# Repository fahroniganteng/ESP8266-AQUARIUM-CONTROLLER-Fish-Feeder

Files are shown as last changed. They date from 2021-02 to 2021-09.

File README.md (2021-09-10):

# ESP8266-AQUARIUM-CONTROLLER-Fish-Feeder
Control aquarium with ESP8266 - Fish Feeder, Lamp, Pump

## Feature
- Wifi connection
- Web base admin
- Offline / Online mode
- Standalone (required NTP connection in online mode)
- Pump control (ON/OFF).
- Fish feeder schedule.
- RGB lamp control & schedule ON/OFF in online mode.

## Demo
DEMO (https://youtu.be/GxMegb_iBR0)

## Instalation guide
DEMO (https://youtu.be/HuCPMu3hP7A)
> video in indonesian language

- Install arduino IDE from [arduino web](https://www.arduino.cc/)
- Install driver CH340 [check here](https://learn.sparkfun.com/tutorials/how-to-install-ch340-drivers/all)
- Upload sketch :
	- Add ESP8266 board to arduino IDE [check here](https://github.com/esp8266/Arduino)
	- Upload sketch
- Upload HTML file:
	- Install filesystem plugin to arduino IDE [check here](https://github.com/esp8266/arduino-esp8266fs-plugin)
	- Upload HTML file
	> NOTE:  
	> When uploading filesystem make sure the serial monitor (arduino IDE) is closed

## Components
- ESP8266 board (Wemos, nodemcu, etc)
- Led strip 12v (common anode)
- Mosfet N channel (can use ULN2003 if using short led strip/ low ampere)
- Servo SG90
- Relay modul / shield
- Mechanical feeder (use 3D printer, check model in 3D folder)
- 12V Power supply
- 5V power supply (or use step down 12v to 5v)
- Box (optional, check model in 3D folder)

## Wiring
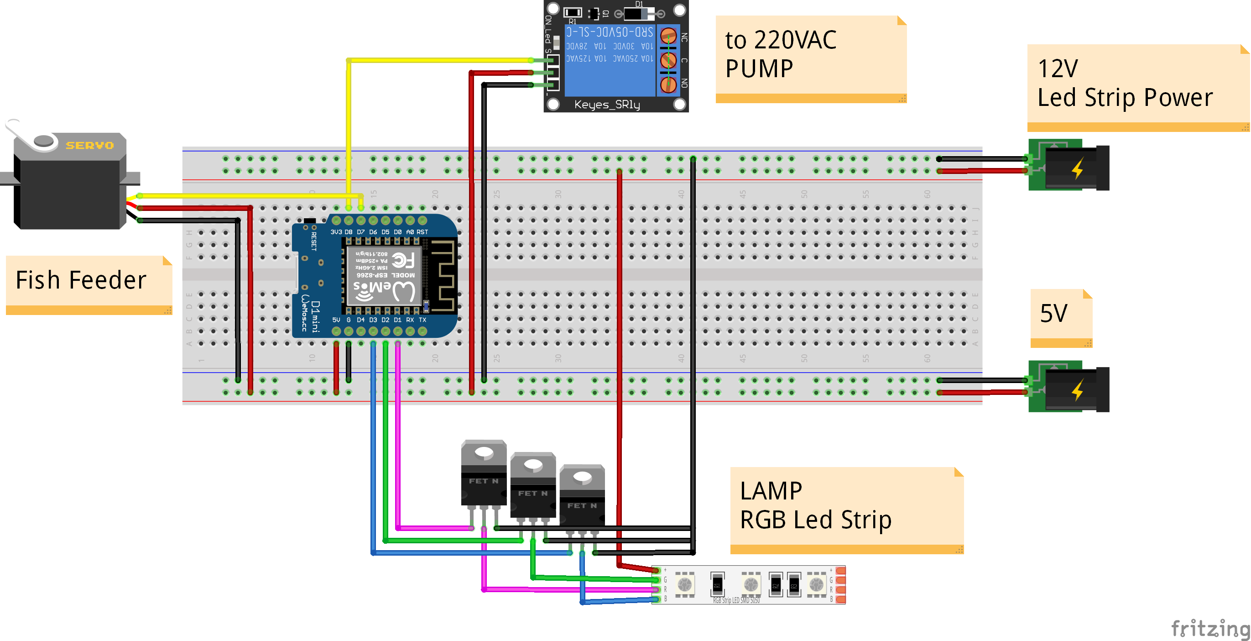
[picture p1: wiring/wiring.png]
Wiring

 - D1 : Red led strip
 - D2 : Green led strip
 - D3 : Blue led strip
 - D7 : Servo
 - D8 : Relay

## Mechanical Feeder
Mechanical feeder made with 3d printer, check on 3D folder for models.
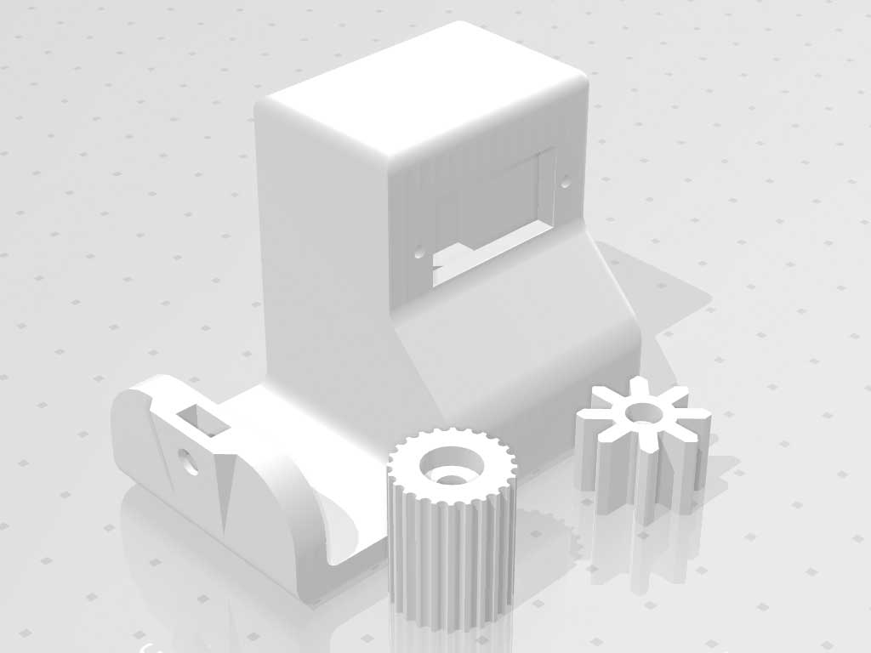
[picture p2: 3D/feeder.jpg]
feeder1

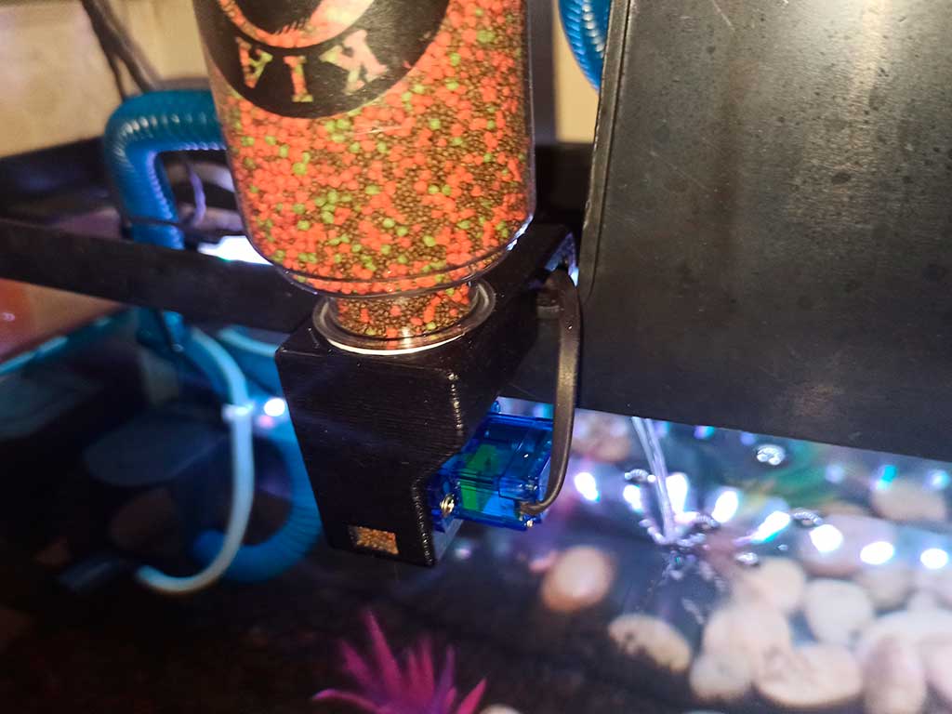
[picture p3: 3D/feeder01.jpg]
feeder2

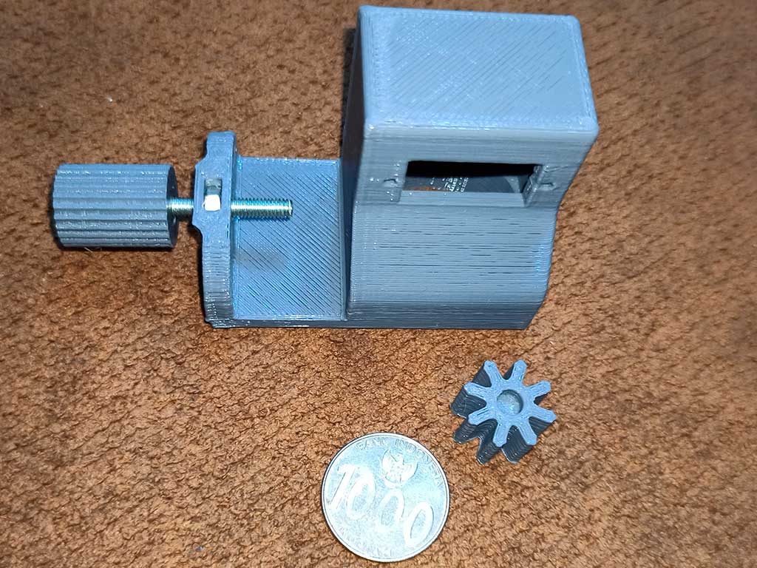
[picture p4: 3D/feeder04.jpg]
feeder3

> Mechanical feeder remixes from [here](https://www.thingiverse.com/thing:2921447)
## Usage
Default setting is offline mode (device becomes wifi access point) :
- Connect to board with wifi 
	- Default SSID = AQUARIUM
	- No password
- Open web address http://10.10.10.10/
> NOTE:  
> ESP8266 is low processor, too many web connections will be slow.

Set up wifi connection and NTP to change online mode.  
- offline mode ==> schedule feeders based on duration.
- online mode ==> schedule feeders based on time.

If internet connection down or can't get time from NTP server, it will auto switch to offline mode, and duration calculated from last feed.  

## License and credits
My code under MIT license, other libraries follow their own license.
- Timer.h
- NTPClient.h
- Jquery.js
- Bootstrap
- etc...

## Donation  
Support me  
- [Send me coffee](https://sociabuzz.com/fahroniganteng/tribe)
- [or maybe ice cream](https://trakteer.id/fahroniganteng/tip)

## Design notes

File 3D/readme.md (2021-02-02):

# 3D Printer File
## feeder.stl
Fish Feeder
- 1x M4 bolt
- 1x servo SG90

## box.stl
Box for controller
- 2x M3 bolt
- acrylic

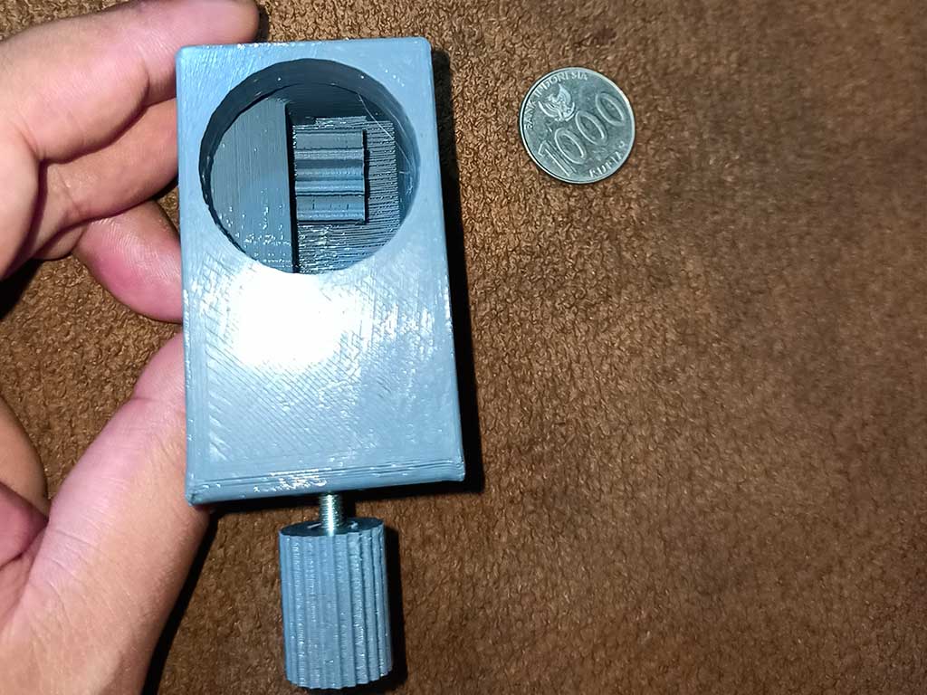
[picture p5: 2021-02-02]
3D/feeder03.jpg

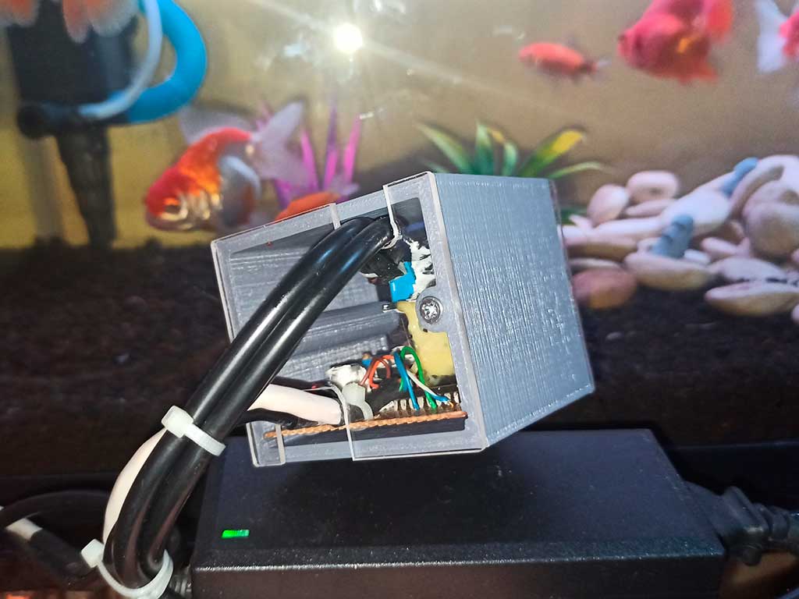
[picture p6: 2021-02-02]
3D/box01.jpg

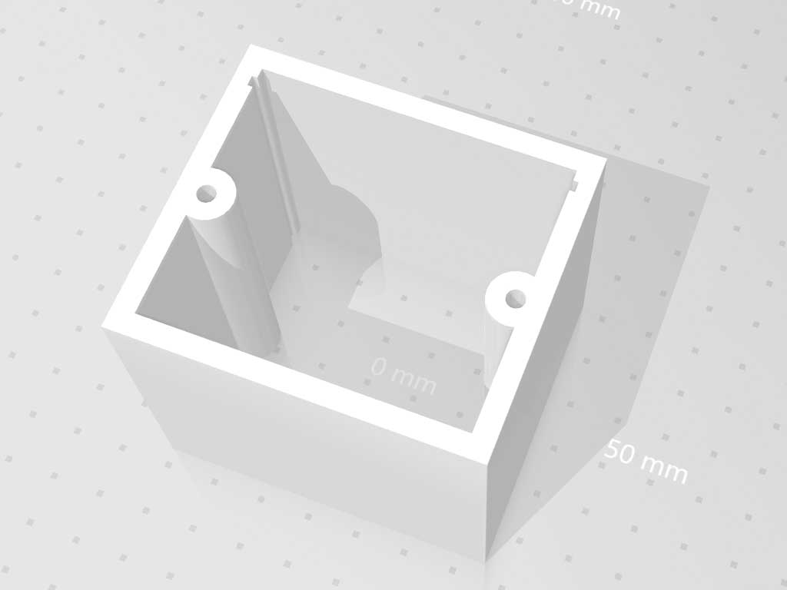
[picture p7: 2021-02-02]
3D/box.jpg

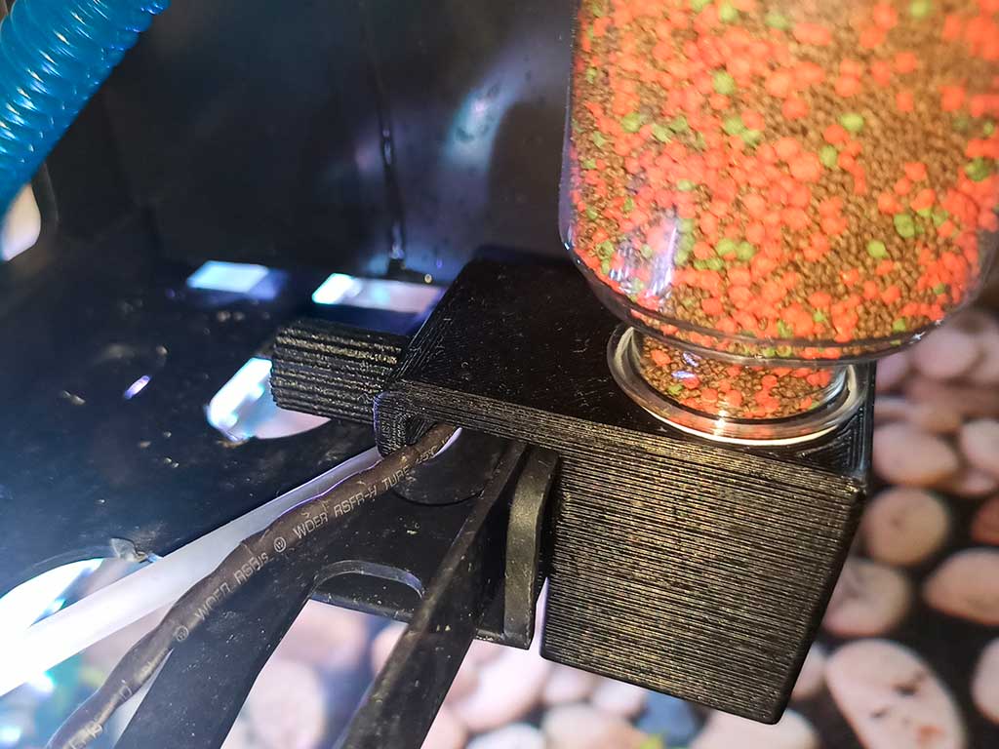
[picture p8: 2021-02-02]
3D/feeder02.jpg

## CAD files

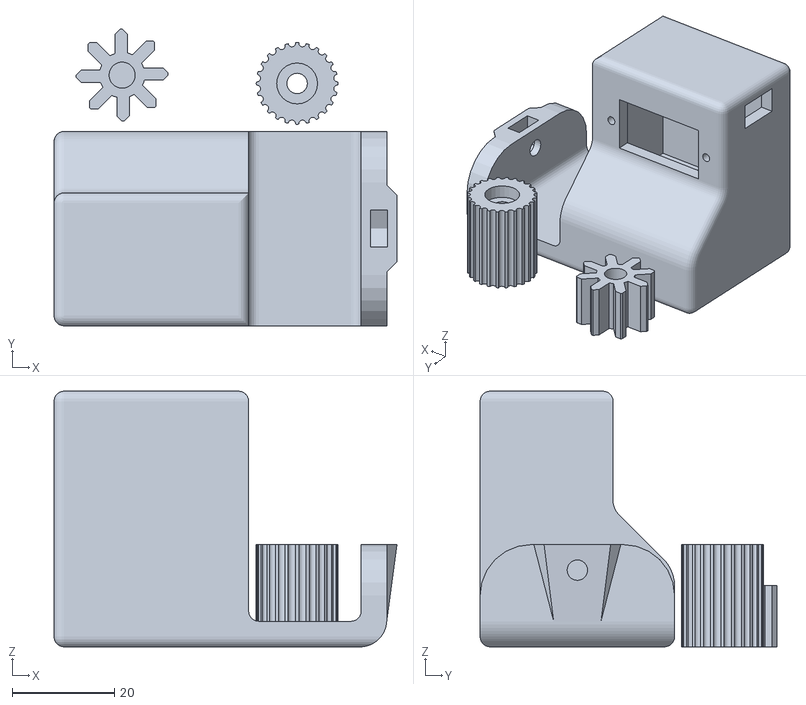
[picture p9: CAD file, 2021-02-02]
3D/feeder.stl
67.0 x 58.0 x 50.0

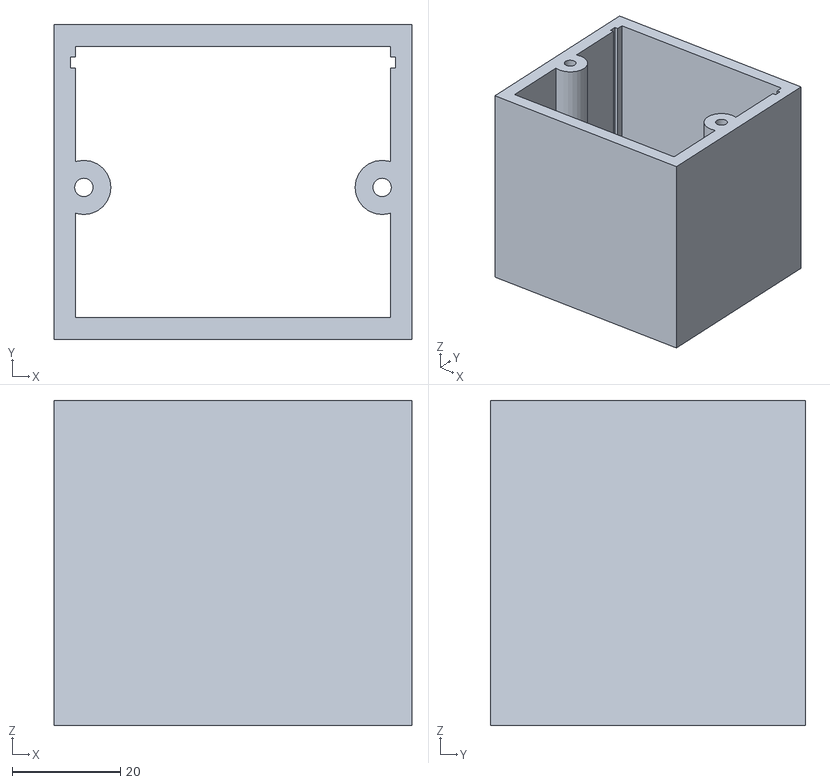
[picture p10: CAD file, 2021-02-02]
3D/box.stl
66.0 x 58.0 x 60.0

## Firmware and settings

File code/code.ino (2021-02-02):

/*
 * AQUARIUM CONTROLLER
 * *********************************************************************************
 * Code by : fahroni|ganteng 
 * Contact me : fahroniganteng@gmail.com
 * License : MIT
 * --------------------------
 * 
 * PIN use on WEMOS D1 Mini
 * D1 : Pin RED led strip
 * D2 : Pin Green led strip
 * D3 : Pin Blue led strip
 * D4 = LED_BUILTIN : not connect ==> for indicator light
 * D7 : Servo
 * D8 : Relay
 * 
 */


#include "NTPClient.h"
#include <ESP8266WiFi.h>
#include <WiFiUdp.h>
#include <ESP8266WebServer.h>
#include <EEPROM.h>
#include "Timer.h"
#include "time.h"
#include <FS.h>   //Include File System Headers
#include <Servo.h>




//Maping PIN ESP8266 board
const int PIN[9] = {D0,D1,D2,D3,D4,D5,D6,D7,D8};// all digital pin ESP8266
const int PIN_LED[3] = {D1,D2,D3}; // to RGB PIN --> LED STRIP is common cathode (-), but if use mosfet will be inverse --> analog write 0 = off, 255 = max brightness
#define PIN_SERVO D7 // to servo
#define PIN_PUMP D8 // to relay

// speed servo ==> ms/degree
#define SERVOSPEED 2.5

// fn get size of int array
#define arrSize(x)   (sizeof(x) / sizeof(x[0]))

// fn Calculate time
#define SECS_PER_MIN  (60UL)
#define SECS_PER_HOUR (3600UL)
#define SECS_PER_DAY  (SECS_PER_HOUR * 24L)

#define getSEC(_time_) (_time_ % SECS_PER_MIN)  
#define getMIN(_time_) ((_time_ / SECS_PER_MIN) % SECS_PER_MIN)
#define getHOUR(_time_) (( _time_% SECS_PER_DAY) / SECS_PER_HOUR)
#define getDAY(_time_) ( _time_ / SECS_PER_DAY)

// Debuging
#define DEBUG 0   // Enable or disable ==> set 1 to enable serial debuging
#if DEBUG
  #define PRINT(s)     { Serial.print(s); }
  #define PRINTLN(s)     { Serial.println(s); }
#else
  #define PRINT(s)
  #define PRINTLN(s)
#endif

//Setting soft AP
const char* ssid = "AQUARIUM";
const char* passphrase = "";//blank = no password
const char* wifiHostName = "AQUARIUM"; //host name device (like computer name if read from network)
IPAddress local_IP(10,10,10,10);
IPAddress gateway(10,10,10,10);
IPAddress subnet(255,255,255,0);
//web server
ESP8266WebServer server(80);

// servo
Servo s;


/*
 * GLOBAL VARIABLE
 * ******************************************************************************************
 */
//Timer ---------------------------------------------------------------
Timer tmr;

//UP time -------------------------------------------------------------
long secUpTime = 0; // counter uptime in second --> default first boot = 0 second
String shUpTime;    // show UP Time (view up time)


//NTP & WIFI ----------------------------------------------------------
WiFiUDP ntpUDP;     // send request time to NTP server
NTPClient timeClient(ntpUDP); 
float timeZone;     // buffer time zona --> if in half hour like GMT -3:30 = -3.5 --> so use float
String e_ssid; // buf SID wifi name
String e_pass; 
String e_ntp; 
String e_gmt; 

// FISH FEEDER ---------------------------------------------------------
String feed_time[5]; // array buffer eeprom feed time {feed1, feed2, ... feed5)
int feed_level,feed_loop,feed_duration; // buffer feed
String nextFeed;

// LAMP ----------------------------------------------------------------
String lamp_time[2];//{off,on}
String lamp_color;
int lamp_status = 1,lamp_brig,lamp_mode,lamp_speed;

// PUMP ----------------------------------------------------------------
int pump_status = 1;

/*
 * NOTE :
 * lamp and pump always start on boot...
 */




/*
 * FUNCTION
 * *****************************************************************************************
 */
// FEEDER -------------------
int secondAfterFeeder = 0;
void feedFish(){
  int moveDegree = map(feed_level,1,10,30,180);
  int moveTime   = SERVOSPEED * moveDegree;
  moveTime       = moveTime<150?150:moveTime;//minimal 150ms
  for(int i=0;i<feed_loop;i++){
    PRINTLN("Feed fish "+String(moveDegree)+" deg");
    s.write(moveDegree);
    delay(moveTime);
    s.write(0);
    delay(moveTime);
  }
  secondAfterFeeder = 0;
}

// UP TIME -------------------
void uptime(){
  char buf[50];//buffer
  secUpTime++; // max long datatype = 2,147,483,647 second = 69 year
  //secUpTime = secUpTime<0?0:secUpTime; // after 2,147,483,647 + 1 = -2147483648 ==> impossible run until 69 year ^___^
  
  snprintf(buf, 50, "%ld Day %02d:%02d:%02d",getDAY(secUpTime),getHOUR(secUpTime),getMIN(secUpTime),getSEC(secUpTime));
  shUpTime = String(buf);
}

// MOVE TO OTHER FILE --------------------------
#include "fnEEPROM.h" // mapping eeprom
#include "fnWifi.h"   // function conection wifi
#include "fnNTP.h"    // get time from NTP
#include "fnLamp.h"   // Lamp handle
#include "fnHtml.h"   // for handle HTML request (from web browser)



// CHECK EVERY 1 SECOND -----------------------
int countApMode = 0;

void check_1s(){
  getNtpDate(); //check NTP
  uptime(); // check uptime
  secondAfterFeeder++;
  
  // IF OFFLINE OR not connect NTP server
  if (WiFi.status() != WL_CONNECTED || ntp_datetime == "--no data--" ){ 
    // run offline fish feeder
    if(feed_duration * 60 * 60 < secondAfterFeeder)
      feedFish();

    // Offline next feed
    char buf[50];//buffer
    int secNextFeed = feed_duration * 60 * 60 - secondAfterFeeder;
    snprintf(buf, 50, "%02d:%02d:%02d",getHOUR(secNextFeed),getMIN(secNextFeed),getSEC(secNextFeed));
    nextFeed = buf;

    // try connect every 60 second, if SSID in EEPROM is set. ==> not set = "__DEFAULT_WIFI__"
    if(e_ssid!="__DEFAULT_WIFI__" && countApMode > 60){
      connectWifi();
      countApMode=0; // counting form zero again, until 60 second try connect again...
    }
    else 
      countApMode++;
  }
  else {
    //check every minutes (ONLINE MODE)
    if(arr_time[2]=="00"){
      String buf = arr_time[0] + ":" + arr_time[1];
      // check feed schedule 
      for(int i=0; i<5; i++){
        if(feed_time[i] == buf){
          feedFish();
          break;
        }
      }
      //check lamp schedule ==> if schedule ON same with OFF ==> lamp always ON
      if(lamp_time[1]==buf)fn_RGBstart();
      else if(lamp_time[0]==buf)fn_RGBstop();
    }
    countApMode=0;
  }
}











void setup() {
  //for debug
  Serial.begin(115200);

  //read EEPROM data
  EEPROM.begin(512);
  readAllDataEEPROM();

  // for file system (html and friends on flash memory)
  SPIFFS.begin();

  // set all digital pin OUTPUT
  for(int i=0; i<arrSize(PIN); i++){
    pinMode(PIN[i], OUTPUT);
    digitalWrite(PIN[i], LOW);
  }

  // Servo PIN
  s.attach(PIN_SERVO);
  s.write(0);
  
  // Turn ON Pump
  digitalWrite(PIN_PUMP,HIGH);

  // Turn ON Lamp
  fn_RGBstart();
  
  //Wifi start
  WiFi.persistent(false);
  PRINTLN("Connecting wifi...");
  connectWifi();
  
  //start http server
  server.begin();
  serverOnHandleClient();
  PRINTLN("HTTP server started");
  
  //turn off LED_BUILTIN; --> LED_BUILTIN = D4 (WEMOS D1 MINI)
  digitalWrite(LED_BUILTIN,HIGH);// HIGH = off --> i dont know why... :D
  
  //NTP
  ntpInit();
  delay(1000);
  tmr.every(3600000,[](){//force update NTP every 1 hour
    timeClient.forceUpdate();
  });

  // Check every 1 second
  delay(100);
  tmr.every(1000,check_1s);
}
void loop() {
  tmr.update(); // update timer
  server.handleClient(); // check http client request
}

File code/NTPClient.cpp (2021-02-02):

/**
 * The MIT License (MIT)
 * Copyright (c) 2015 by Fabrice Weinberg
 *
 * Permission is hereby granted, free of charge, to any person obtaining a copy
 * of this software and associated documentation files (the "Software"), to deal
 * in the Software without restriction, including without limitation the rights
 * to use, copy, modify, merge, publish, distribute, sublicense, and/or sell
 * copies of the Software, and to permit persons to whom the Software is
 * furnished to do so, subject to the following conditions:
 * The above copyright notice and this permission notice shall be included in all
 * copies or substantial portions of the Software.
 * THE SOFTWARE IS PROVIDED "AS IS", WITHOUT WARRANTY OF ANY KIND, EXPRESS OR
 * IMPLIED, INCLUDING BUT NOT LIMITED TO THE WARRANTIES OF MERCHANTABILITY,
 * FITNESS FOR A PARTICULAR PURPOSE AND NONINFRINGEMENT. IN NO EVENT SHALL THE
 * AUTHORS OR COPYRIGHT HOLDERS BE LIABLE FOR ANY CLAIM, DAMAGES OR OTHER
 * LIABILITY, WHETHER IN AN ACTION OF CONTRACT, TORT OR OTHERWISE, ARISING FROM,
 * OUT OF OR IN CONNECTION WITH THE SOFTWARE OR THE USE OR OTHER DEALINGS IN THE
 * SOFTWARE.
 */

#include "NTPClient.h"

NTPClient::NTPClient(UDP& udp) {
  this->_udp            = &udp;
}

NTPClient::NTPClient(UDP& udp, long timeOffset) {
  this->_udp            = &udp;
  this->_timeOffset     = timeOffset;
}

NTPClient::NTPClient(UDP& udp, const char* poolServerName) {
  this->_udp            = &udp;
  this->_poolServerName = poolServerName;
}

NTPClient::NTPClient(UDP& udp, const char* poolServerName, long timeOffset) {
  this->_udp            = &udp;
  this->_timeOffset     = timeOffset;
  this->_poolServerName = poolServerName;
}

NTPClient::NTPClient(UDP& udp, const char* poolServerName, long timeOffset, unsigned long updateInterval) {
  this->_udp            = &udp;
  this->_timeOffset     = timeOffset;
  this->_poolServerName = poolServerName;
  this->_updateInterval = updateInterval;
}

void NTPClient::begin() {
  this->begin(NTP_DEFAULT_LOCAL_PORT);
}

void NTPClient::begin(int port) {
  this->_port = port;

  this->_udp->begin(this->_port);

  this->_udpSetup = true;
}

bool NTPClient::forceUpdate() {
  #ifdef DEBUG_NTPClient
    Serial.println("Update from NTP Server");
  #endif
  this->sendNTPPacket();

  // Wait till data is there or timeout...
  byte timeout = 0;
  int cb = 0;
  do {
    delay ( 10 );
    cb = this->_udp->parsePacket();
    if (timeout > 100) return false; // timeout after 1000 ms --> default 100 (1000ms) tak ganti 10 (100ms)
    timeout++;
  } while (cb == 0);
  this->_lastUpdate = millis() - (10 * (timeout + 1)); // Account for delay in reading the time

  this->_udp->read(this->_packetBuffer, NTP_PACKET_SIZE);

  unsigned long highWord = word(this->_packetBuffer[40], this->_packetBuffer[41]);
  unsigned long lowWord = word(this->_packetBuffer[42], this->_packetBuffer[43]);
  // combine the four bytes (two words) into a long integer
  // this is NTP time (seconds since Jan 1 1900):
  unsigned long secsSince1900 = highWord << 16 | lowWord;

  this->_currentEpoc = secsSince1900 - SEVENZYYEARS;
  return true;
}

bool NTPClient::update() {
  if ((millis() - this->_lastUpdate >= this->_updateInterval)     // Update after _updateInterval
    || this->_lastUpdate == 0) {                                // Update if there was no update yet.
    if (!this->_udpSetup) this->begin();                         // setup the UDP client if needed
    return this->forceUpdate();
  }
  return true;
}

unsigned long NTPClient::getEpochTime() const {
  return this->_timeOffset + // User offset
         this->_currentEpoc + // Epoc returned by the NTP server
         ((millis() - this->_lastUpdate) / 1000); // Time since last update
}

int NTPClient::getDay() const {
  return (((this->getEpochTime()  / 86400L) + 4 ) % 7); //0 is Sunday
}
int NTPClient::getHours() const {
  return ((this->getEpochTime()  % 86400L) / 3600);
}
int NTPClient::getMinutes() const {
  return ((this->getEpochTime() % 3600) / 60);
}
int NTPClient::getSeconds() const {
  return (this->getEpochTime() % 60);
}

String NTPClient::getFormattedTime() const {
  unsigned long rawTime = this->getEpochTime();
  unsigned long hours = (rawTime % 86400L) / 3600;
  String hoursStr = hours < 10 ? "0" + String(hours) : String(hours);

  unsigned long minutes = (rawTime % 3600) / 60;
  String minuteStr = minutes < 10 ? "0" + String(minutes) : String(minutes);

  unsigned long seconds = rawTime % 60;
  String secondStr = seconds < 10 ? "0" + String(seconds) : String(seconds);

  return hoursStr + ":" + minuteStr + ":" + secondStr;
}

void NTPClient::end() {
  this->_udp->stop();

  this->_udpSetup = false;
}

void NTPClient::setTimeOffset(int timeOffset) {
  this->_timeOffset     = timeOffset;
}

void NTPClient::setUpdateInterval(unsigned long updateInterval) {
  this->_updateInterval = updateInterval;
}

void NTPClient::setPoolServerName(const char* poolServerName) {
//  Serial.println("-------------------------------------------------");
//  Serial.println(poolServerName);
//  Serial.println(this->_poolServerName);

    //==> ini gak jelas data convert an dari string, disini masih kebaca --> di void NTPClient::sendNTPPacket gak kebaca
    //this->_poolServerName = poolServerName; 
    
//     Serial.println(this->_poolServerName);// ini masih baca 

     this->_serverName = String(poolServerName);//ganti pake variable String sekalian --> ngeselin
}
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
